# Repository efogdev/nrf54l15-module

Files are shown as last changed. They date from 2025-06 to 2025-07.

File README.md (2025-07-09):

## Codename "Chinchilla"

### ❗️ DO NOT BUILD ❗️
### ❗️ The design has a critical issue ❗️

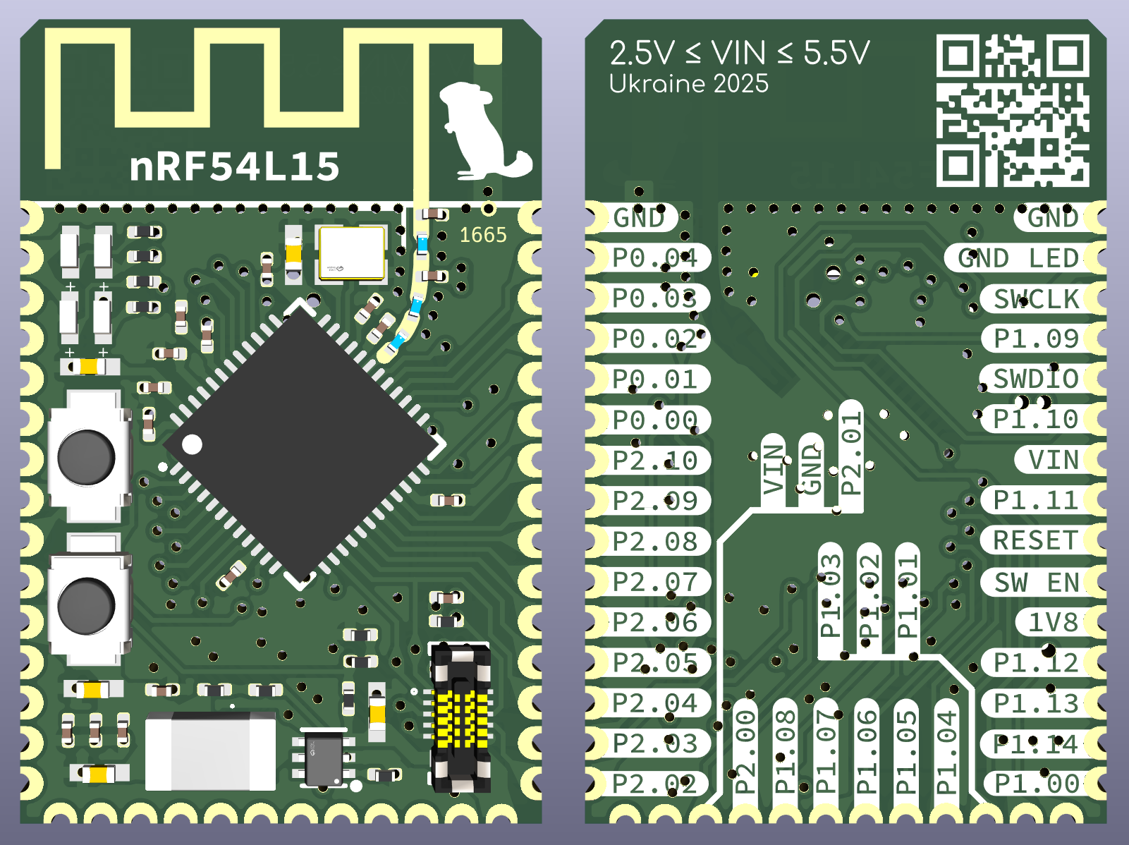
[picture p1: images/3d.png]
3D view


## Features

1. Full IO set: all the GPIO and programming pins are present
2. Compact design: the board is 16.4x25.3 mm with ≈4.8 mm of total height
3. Ultra efficient: featuring TLV62569 with ≥92% efficiency at (almost) any load
4. 1V8 pin can be used as both input (if VIN not connected) and output (up to 1.5A)
5. 4 programmable LEDs (200 µA) that can be isolated to free the pins
6. On-board "reset" switch and an additional general purpose button (High/High-Z)
7. Impedance of (almost) all traces is close to 50Ω
8. Board-to-board connector with programming, power and GPIO pins 

## Stackup

JLC06121H-3313

## Dimensions

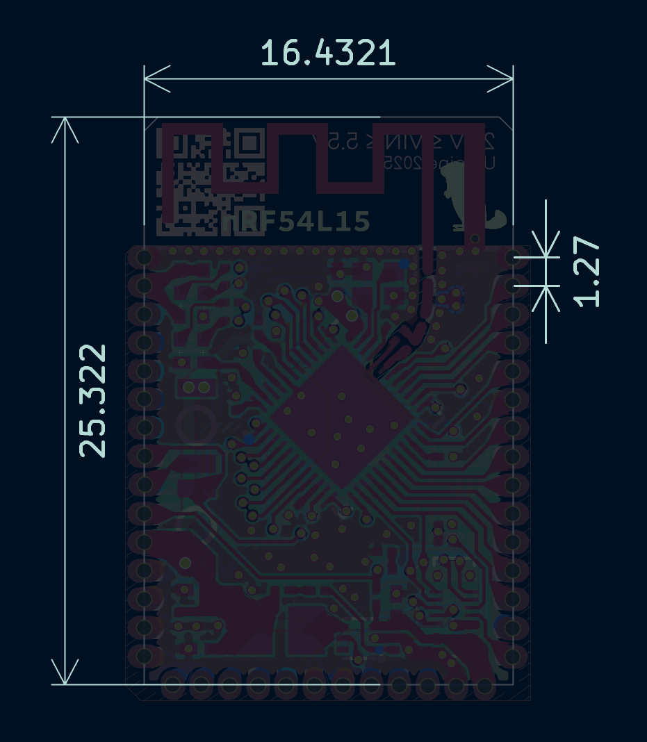
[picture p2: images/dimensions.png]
Dimensions


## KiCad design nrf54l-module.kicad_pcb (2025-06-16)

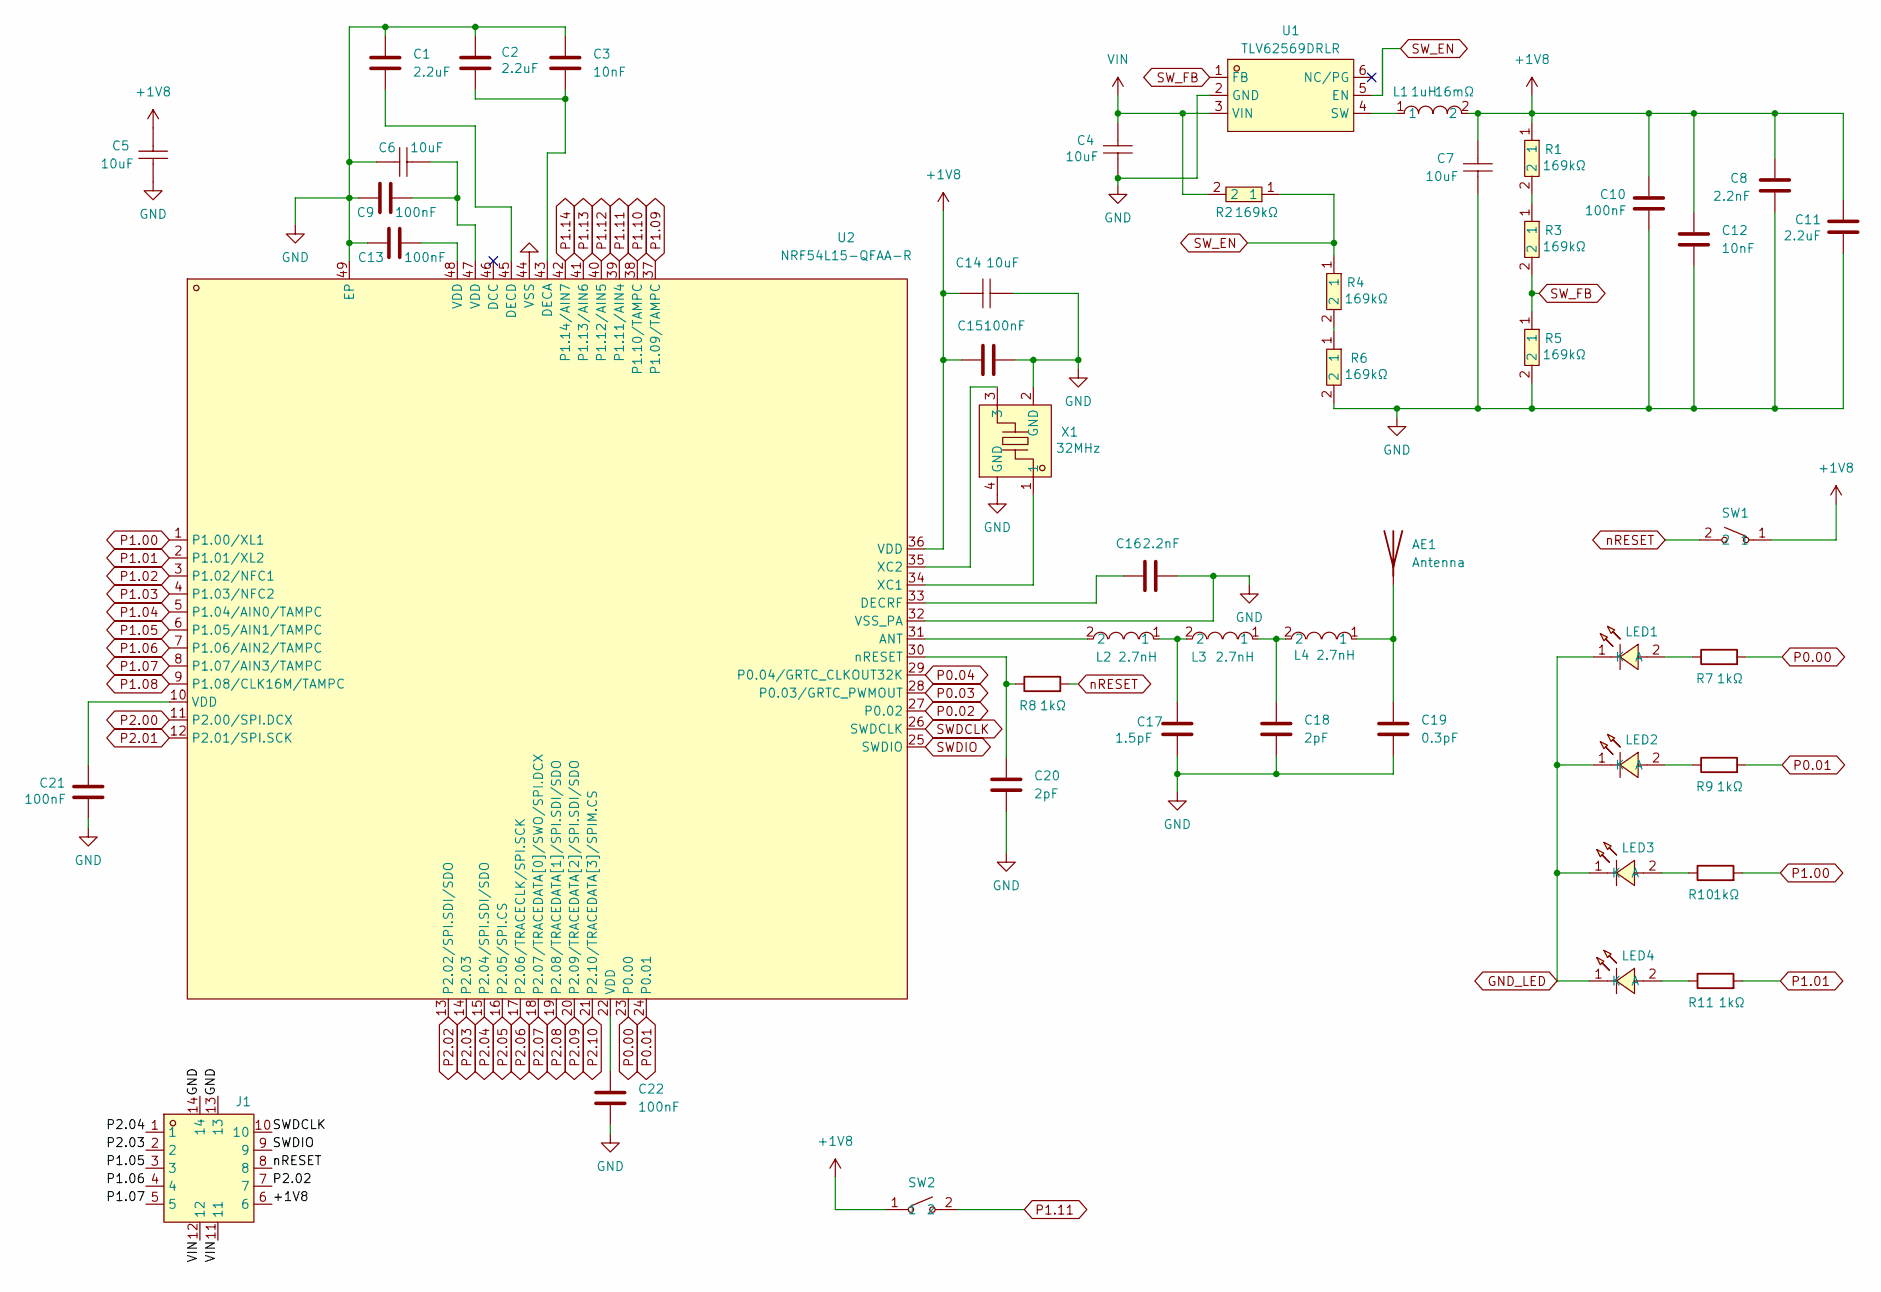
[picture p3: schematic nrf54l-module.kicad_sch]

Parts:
AE1: Antenna; Texas_SWRA117D_2.4GHz_Left
C1, C2, C11: 2.2uF; C_0201_0603Metric; LCSC Part C76933
C3, C12: 10nF; C_0201_0603Metric; LCSC Part C76941
C4, C5, C6, C7, C14: 10uF; C0402; LCSC Part C76991
C8, C16: 2.2nF; C_0201_0603Metric; LCSC Part C97860
C9, C10, C13, C15, C21, C22: 100nF; C_0201_0603Metric; LCSC Part C668346
C17: 1.5pF; C_0201_0603Metric; LCSC Part C88913
C18, C20: 2pF; C_0201_0603Metric; LCSC Part C426046
C19: 0.3pF; C_0201_0603Metric; LCSC Part C76927
J1: BM28B0.6-10DS/2-0.35V(51); CONN-SMD_BM28B0.6-10DS-2-0.35V-51; LCSC Part C424563
L1: 1uH; L1008; LCSC Part C22400405
L2, L3, L4: MLG0603P2N7CT000; L0201; LCSC Part C76752
LED1, LED2, LED3, LED4: TZ-P2-0402RTIA1-0.45T; LED0402-RD_RED; LCSC Part C779449
R1, R2, R3, R4, R5, R6: RC0402FR-07160KL; R_0201_0603Metric; LCSC Part C166333
R7, R8, R9, R10, R11: 1kΩ; R_0201_0603Metric; LCSC Part C270365
SW1, SW2: KEY-SMD_B3U-1000PM; LCSC Part C231329
U1: TLV62569DRLR; SOT-563_L1.6-W1.2-P0.50-LS1.6-BL; LCSC Part C163217
U2: NRF54L15-QFAA-R; QFN-48_L6.0-W6.0-P0.40-TL-EP4.6; LCSC Part C42458750
X1: XL7EL89CKI-111YLC-32M; CRYSTAL-SMD_4P-L2.0-W1.6-BL; LCSC Part C2965582

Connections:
+1V8: C5.1, C7.1, C8.2, C10.2, C11.2, C12.1, C14.1, C15.1, J1.6, L1.2, R1.1, SW1.1, SW2.1, U2.36 (VDD)
GND: AE1.2, C1.1, C2.1, C3.1, C4.1, C5.2, C6.1, C7.2, C8.1, C9.1, C10.1, C11.1, C12.2, C13.2, C14.2, C15.2, C16.2, C17.2, C18.2, C19.2, C20.2, C21.1, C22.2, J1.13, J1.14, R5.2, R6.2, U1.2 (GND), U2.32 (VSS_PA), U2.44 (VSS), U2.49 (EP), X1.2 (GND), X1.4 (GND)
GND_LED: LED1.1 (K), LED2.1 (K), LED3.1 (K), LED4.1 (K)
unnamed: AE1.1 (A), C19.1, L4.1
unnamed: C6.2, C9.2, U2.47 (VDD)
unnamed: C13.1, U2.48 (VDD)
unnamed: C17.1, L2.1, L3.2
unnamed: C18.1, L3.1, L4.2
unnamed: C21.2, U2.10 (VDD)
unnamed: C22.1, U2.22 (VDD)
unnamed: LED1.2 (A), R7.1
unnamed: LED2.2 (A), R9.1
unnamed: LED3.2 (A), R10.1
unnamed: LED4.2 (A), R11.1
unnamed: R1.2, R3.1
unnamed: R4.2, R6.1
unnamed: L1.1, U1.4 (SW)
unnamed: L2.2, U2.31 (ANT)
unnamed: C2.2, C3.2, U2.43 (DECA)
unnamed: C1.2, U2.45 (DECD)
unnamed: C16.1, U2.33 (DECRF)
unnamed: U2.34 (XC1), X1.1
unnamed: U2.35 (XC2), X1.3
unnamed: C20.1, R8.1, U2.30 (nRESET)
P0.00: R7.2, U2.23 (P0.00)
P0.01: R9.2, U2.24 (P0.01)
P0.02: U2.27 (P0.02)
P0.03: U2.28 (P0.03/GRTC_PWMOUT)
P0.04: U2.29 (P0.04/GRTC_CLKOUT32K)
P1.00: R10.2, U2.1 (P1.00/XL1)
P1.01: R11.2, U2.2 (P1.01/XL2)
P1.02: U2.3 (P1.02/NFC1)
P1.03: U2.4 (P1.03/NFC2)
P1.04: U2.5 (P1.04/AIN0/TAMPC)
P1.05: J1.3, U2.6 (P1.05/AIN1/TAMPC)
P1.06: J1.4, U2.7 (P1.06/AIN2/TAMPC)
P1.07: J1.5, U2.8 (P1.07/AIN3/TAMPC)
P1.08: U2.9 (P1.08/CLK16M/TAMPC)
P1.09: U2.37 (P1.09/TAMPC)
P1.10: U2.38 (P1.10/TAMPC)
P1.11: SW2.2, U2.39 (P1.11/AIN4)
P1.12: U2.40 (P1.12/AIN5)
P1.13: U2.41 (P1.13/AIN6)
P1.14: U2.42 (P1.14/AIN7)
P2.00: U2.11 (P2.00/SPI.DCX)
P2.01: U2.12 (P2.01/SPI.SCK)
P2.02: J1.7, U2.13 (P2.02/SPI.SDI/SDO)
P2.03: J1.2, U2.14 (P2.03)
P2.04: J1.1, U2.15 (P2.04/SPI.SDI/SDO)
P2.05: U2.16 (P2.05/SPI.CS)
P2.06: U2.17 (P2.06/TRACECLK/SPI.SCK)
P2.07: U2.18 (P2.07/TRACEDATA[0]/SWO/SPI.DCX)
P2.08: U2.19 (P2.08/TRACEDATA[1]/SPI.SDI/SDO)
P2.09: U2.20 (P2.09/TRACEDATA[2]/SPI.SDI/SDO)
P2.10: U2.21 (P2.10/TRACEDATA[3]/SPIM.CS)
SWDCLK: J1.10, U2.26 (SWDCLK)
SWDIO: J1.9, U2.25 (SWDIO)
SW_EN: R2.1, R4.1, U1.5 (EN)
SW_FB: R3.2, R5.1, U1.1 (FB)
VIN: C4.2, J1.11, J1.12, R2.2, U1.3 (VIN)
nRESET: J1.8, R8.2, SW1.2

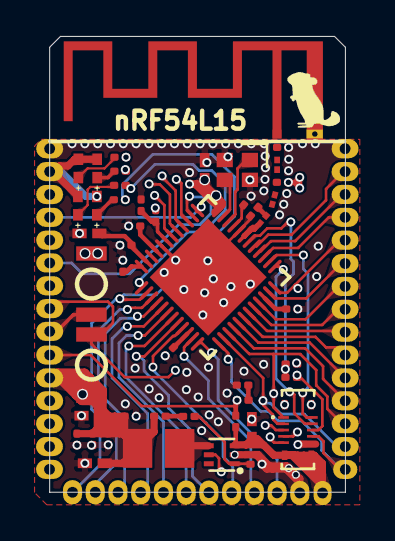
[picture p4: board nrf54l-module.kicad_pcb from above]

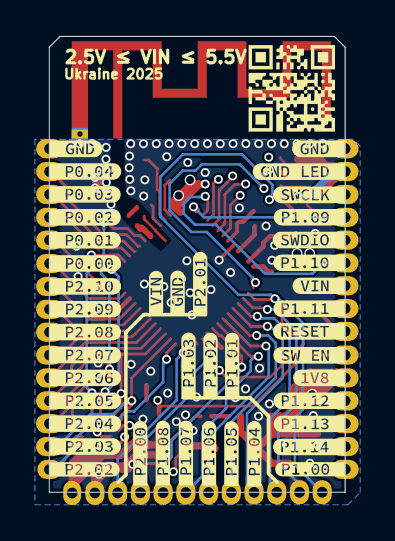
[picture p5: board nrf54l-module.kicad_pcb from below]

Board: 6 copper layers, 16.4 x 25.3 mm, 90 parts (42 on the bottom side), 41 nets.

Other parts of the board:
kibuzzard-684F74F9: G***; kibuzzard-684F74F9
kibuzzard-684F75DA: G***; kibuzzard-684F75DA
kibuzzard-684F75DE: G***; kibuzzard-684F75DE
kibuzzard-684F75E1: G***; kibuzzard-684F75E1
kibuzzard-684F75E4: G***; kibuzzard-684F75E4
kibuzzard-684F75E9: G***; kibuzzard-684F75E9
kibuzzard-684F75ED: G***; kibuzzard-684F75ED
kibuzzard-684F75F1: G***; kibuzzard-684F75F1
kibuzzard-684F75F7: G***; kibuzzard-684F75F7
kibuzzard-684F75FF: G***; kibuzzard-684F75FF
kibuzzard-684F750C: G***; kibuzzard-684F750C
kibuzzard-684F751D: G***; kibuzzard-684F751D
kibuzzard-684F753F: G***; kibuzzard-684F753F
kibuzzard-684F761F: G***; kibuzzard-684F761F
kibuzzard-684F7560: G***; kibuzzard-684F7560
kibuzzard-684F7579: G***; kibuzzard-684F7579
kibuzzard-684F7581: G***; kibuzzard-684F7581
kibuzzard-684F7617: G***; kibuzzard-684F7617
kibuzzard-68448D45: G***; kibuzzard-68448D45
kibuzzard-68448D82: G***; kibuzzard-68448D82
kibuzzard-68448D96: G***; kibuzzard-68448D96
kibuzzard-68448DA6: G***; kibuzzard-68448DA6
kibuzzard-68463A68: G***; kibuzzard-68463A68
kibuzzard-68478D5A: G***; kibuzzard-68478D5A
kibuzzard-68478D5E: G***; kibuzzard-68478D5E
kibuzzard-68478D8D: G***; kibuzzard-68478D8D
kibuzzard-68478D9B: G***; kibuzzard-68478D9B
kibuzzard-68478D71: G***; kibuzzard-68478D71
kibuzzard-68478D86: G***; kibuzzard-68478D86
kibuzzard-68478D98: G***; kibuzzard-68478D98
kibuzzard-684623CD: G***; kibuzzard-684623CD
kibuzzard-6844924F: G***; kibuzzard-6844924F
kibuzzard-6844930A: G***; kibuzzard-6844930A
kibuzzard-6844930F: G***; kibuzzard-6844930F
kibuzzard-6844931D: G***; kibuzzard-6844931D
kibuzzard-68449253: G***; kibuzzard-68449253
kibuzzard-68449303: G***; kibuzzard-68449303
kibuzzard-68449307: G***; kibuzzard-68449307
kibuzzard-68449316: G***; kibuzzard-68449316
kibuzzard-68449351: G***; kibuzzard-68449351
kibuzzard-68449359: G***; kibuzzard-68449359
kibuzzard-68449360: G***; kibuzzard-68449360

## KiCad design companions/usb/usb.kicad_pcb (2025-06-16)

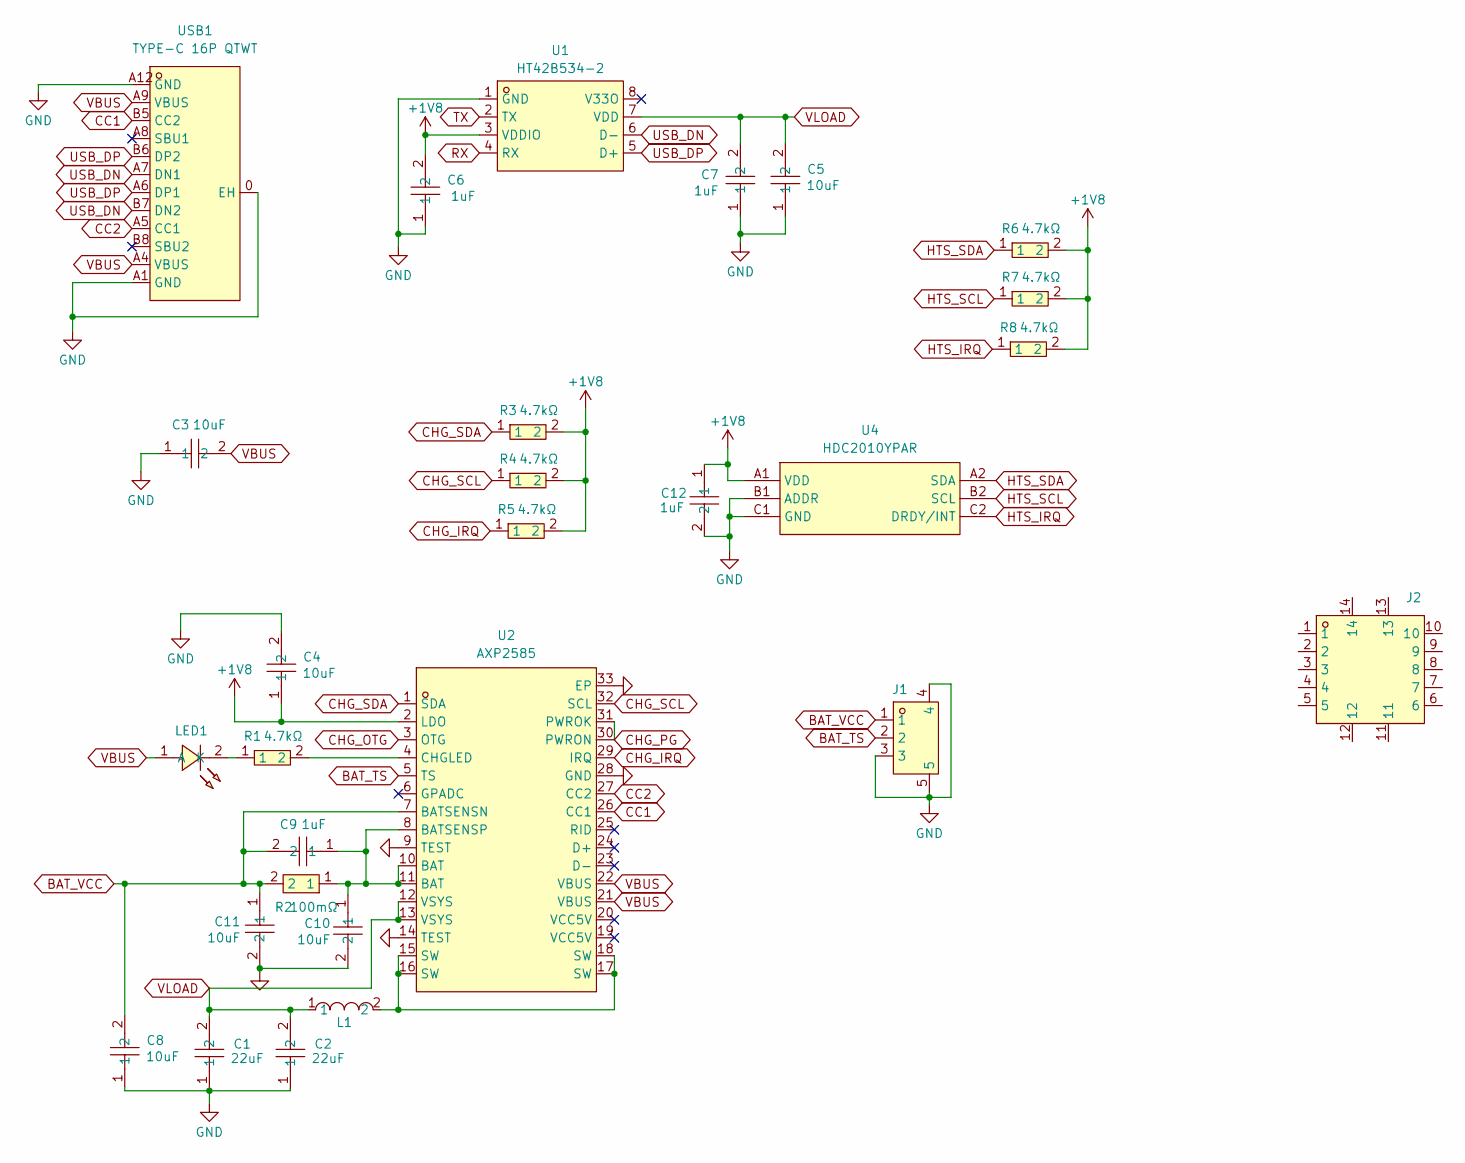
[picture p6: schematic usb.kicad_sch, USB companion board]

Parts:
C1, C2: GRM155R60J226ME11D; C0402; LCSC Part C415703
C3, C4, C5, C8, C10, C11: CL05A106MP5NUNC_C315248; C0402; LCSC Part C315248
C6, C7, C9, C12: CL03A105MQ3CSNH; C_0201_0603Metric; LCSC Part C53067
J1: HC-1.0-3PWT; CONN-SMD_3P-P1.0-HC-1.0-3PWT; LCSC Part C2845362
J2: BM28B0.6-10DP/2-0.35V(51); CONN-SMD_BM28B0.6-10DP-2-0.35V-51; LCSC Part C424562
L1: FTC252012S1R0MBCD; L1008; LCSC Part C22400405
LED1: XL-0201SURC; LED-SMD_L0.65-W0.35-P0.41_XL-0201SURC; LCSC Part C3646923
R1, R3, R4, R5, R6, R7, R8: CRCW02014K70FKED; R_0201_0603Metric; LCSC Part C3000902
R2: FRM121WFR100TM; R1206; LCSC Part C7467250
U1: HT42B534-2; SOP-8_L4.9-W3.9-P1.27-LS6.0-BL; LCSC Part C493294
U2: AXP2585; QFN-32_L5.0-W5.0-P0.40-TL-EP2.9; LCSC Part C20199912
U4: HDC2010YPAR; DSBGA-6_L1.5-W1.5-P0.50-BL; LCSC Part C477922
USB1: TYPE-C 16P QTWT; USB-TYPE-C-SMD_TYPE-C-16P-QTWT; LCSC Part C5187472

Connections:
+1V8: C4.1, C6.2, C12.1, R3.2, R4.2, R5.2, R6.2, R7.2, R8.2, U1.3 (VDDIO), U2.2 (LDO), U4.A1 (VDD)
BAT_TS: J1.2, U2.5 (TS)
BAT_VCC: C8.2, C9.2, C11.1, J1.1, R2.2, U2.7 (BATSENSN)
CC1: U2.26 (CC1), USB1.B5 (CC2)
CC2: U2.27 (CC2), USB1.A5 (CC1)
CHG_IRQ: R5.1, U2.29 (IRQ)
CHG_OTG: U2.3 (OTG)
CHG_PG: U2.30 (PWRON), U2.31 (PWROK)
CHG_SCL: R4.1, U2.32 (SCL)
CHG_SDA: R3.1, U2.1 (SDA)
GND: C1.1, C2.1, C3.1, C4.2, C5.1, C6.1, C7.1, C8.1, C10.2, C11.2, C12.2, J1.3, J1.4, J1.5, U1.1 (GND), U2.9 (TEST), U2.14 (TEST), U2.28 (GND), U2.33 (EP), U4.B1 (ADDR), U4.C1 (GND), USB1.0 (EH), USB1.A1 (GND), USB1.A12 (GND)
HTS_IRQ: R8.1, U4.C2 (DRDY/INT)
HTS_SCL: R7.1, U4.B2 (SCL)
HTS_SDA: R6.1, U4.A2 (SDA)
unnamed: L1.2, U2.15 (SW), U2.16 (SW), U2.17 (SW), U2.18 (SW)
unnamed: LED1.2 (K), R1.1
unnamed: C9.1, C10.1, R2.1, U2.8 (BATSENSP), U2.10 (BAT), U2.11 (BAT)
unnamed: R1.2, U2.4 (CHGLED)
RX: U1.4 (RX)
TX: U1.2 (TX)
USB_DN: U1.6 (D-), USB1.A7 (DN1), USB1.B7 (DN2)
USB_DP: U1.5 (D+), USB1.A6 (DP1), USB1.B6 (DP2)
VBUS: C3.2, LED1.1 (A), U2.21 (VBUS), U2.22 (VBUS), USB1.A4 (VBUS), USB1.A9 (VBUS)
VLOAD: C1.2, C2.2, C5.2, C7.2, L1.1, U1.7 (VDD), U2.12 (VSYS), U2.13 (VSYS)

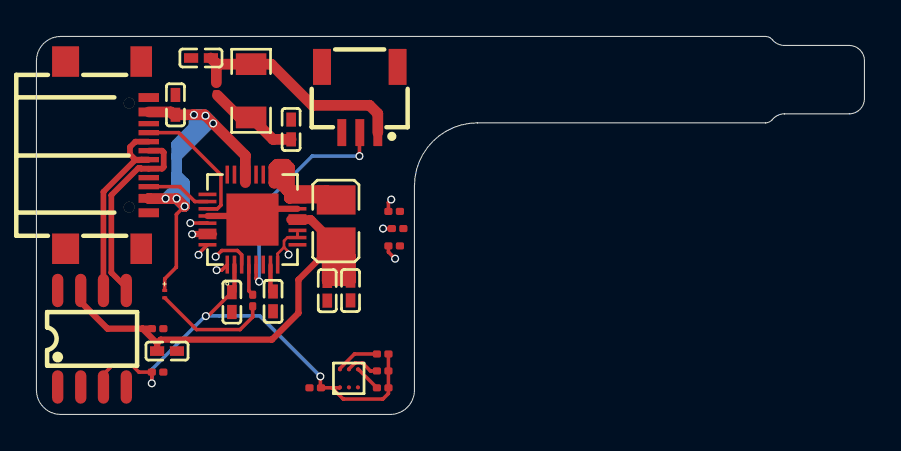
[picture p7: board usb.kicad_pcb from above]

Board: 2 copper layers, 46.0 x 21.0 mm, 28 parts (1 on the bottom side), 21 nets.

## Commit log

2025-06-07 feat: initial commit
    [nrf54l-module.kicad_pcb, nrf54l-module.kicad_sch]
2025-06-07 feat: back silkscreen
    [nrf54l-module.kicad_pcb]
2025-06-07 bugfix: GND pad
    [nrf54l-module.kicad_pcb]
2025-06-07 chore: refactoring
    [nrf54l-module.kicad_pcb, nrf54l-module.kicad_sch]
2025-06-07 bugfix: antenna design
    [nrf54l-module.kicad_pcb]
2025-06-08 feat: chinchilla
    [nrf54l-module.kicad_pcb]
2025-06-08 bugfix: DRC
    [nrf54l-module.kicad_pcb, nrf54l-module.kicad_sch]
2025-06-08 feat: dimensions
    [nrf54l-module.kicad_pcb]
2025-06-08 feat: symbol and footprint
    [nrf54l-module.kicad_pcb]
2025-06-08 feat: 1.27 mm pitch
    [nrf54l-module.kicad_pcb, nrf54l-module.kicad_sch]
2025-06-09 feat: updatd symbol and footprint
    [nrf54l-module.kicad_pcb]
2025-06-09 feat: additinal button on P1.12
    [nrf54l-module.kicad_pcb, nrf54l-module.kicad_sch]
2025-06-09 feat: 6 layer because it's cheaper lol wtf
    [nrf54l-module.kicad_pcb, nrf54l-module.kicad_sch]
2025-06-14 chore: checkpoint
    [nrf54l-module.kicad_pcb, nrf54l-module.kicad_sch, usb-and-battery-companion.kicad_pcb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]
2025-06-16 feat: panel for github bug
    [nrf54l-module.kicad_pcb]
2025-07-09 bugfix(critical): 1.8V power to VDD
    [nrf54l-module.kicad_sch]
